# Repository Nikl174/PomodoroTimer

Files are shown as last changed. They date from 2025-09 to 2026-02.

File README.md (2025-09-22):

# Pomodoro Timer

A little USB A timer user for the [Pomdoro Technique](https://en.wikipedia.org/wiki/Pomodoro_Technique).

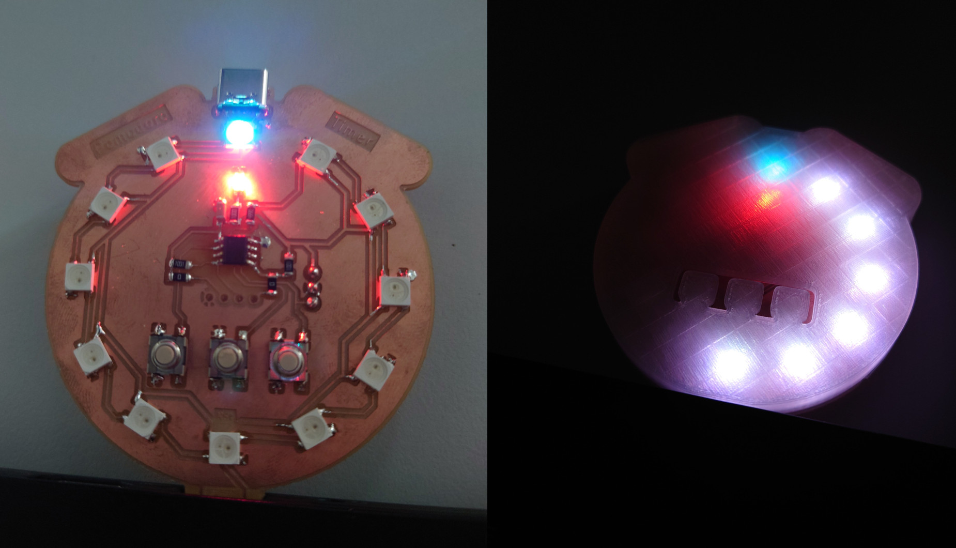
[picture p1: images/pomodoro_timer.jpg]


## Features

- small and powerful ATTiny412 as MCU
- 12 WS2813B RGB LEDs
- 3 Buttons
- I2C Header for playing around
- power over USB C or integrated USB A connector

## Structure

`pcb/`
: KiCAD Files for the electronic schematics and the routed layout

`code/`
: Arduino Code for a simple implementation of the pomodoro technique

`housing/`
: FreeCAD Model for a simple housing for the board

`doc/`
: Datasheets

## Dependencies

### Hardware

- [Components Library](https://gitlab.fabcloud.org/pub/libraries/electronics/kicad) - Component library used for the PCB
- [Serial D11C Programmer](https://gitlab.fabcloud.org/pub/programmers/programmer-serial-d11c) - UPDI Programmer used for flashing together with this [adapter](https://leomcelroy.com/svg-pcb/?file=hello.serial-UPDI.3.js), but also possible with e.g.:
    - [SWD+UART Board](https://gitlab.fabcloud.org/pub/programmers/swd-uart-adapter-xiao-rp2040)
    - [UPDI D11C](https://gitlab.fabcloud.org/pub/programmers/programmer-updi-d11c)
- [MegaTinyCore](https://github.com/SpenceKonde/megaTinyCore/) - arduino library used for programming the ATTiny412
- an arduino environment, more in [here](/code/README.md)
- [KiCAD](https://www.kicad.org/) for editing the PCB/ creating other production files
- [FreeCAD](https://www.freecad.org/) for editing the housing

## BOM Components

| Designator | Footprint | Quantity | Designation |
|---|---|---|---|
| U6,U8,U3,U9,U11,U10,U2,U12,U4,U7,U5,U13 | LED_ADDR_Worldsemi_WS2812B | 12 | WS2812B |
| R2,R7 | R_1206 | 2 | 0R |
| J2 | PinHeader_01x04_P2.54mm_Vertical_THT_D1.4mm | 1 | I2C Header |
| P1 | Conn_USB_A_Plain | 1 | Conn_USB_A_Plain |
| C3 | C_1206 | 1 | 100nF |
| R3 | R_1206 | 1 | 100R |
| SW3 | Button_Omron_B3SN_6.0x6.0mm | 1 | Restart |
| R6,R1 | R_1206 | 2 | 1kR |
| D4 | LED_1206 | 1 | Power LED |
| SW1 | Button_Omron_B3SN_6.0x6.0mm | 1 | Start/Stop |
| U1 | SOIC-8_3.9x4.9mm_P1.27mm | 1 | ATtiny412 |
| J1 | PinHeader_01x03_P2.54mm_Vertical_THT_D1.4mm | 1 | UPDI Flash Header |
| J3 | Conn_USB_C_Socket_GCT_USB4125-GF-A-0190 | 1 | Conn_USB_C_Socket_PowerOnly |
| R5 | R_1206 | 1 | 499R |
| SW2 | Button_Omron_B3SN_6.0x6.0mm | 1 | Skip |

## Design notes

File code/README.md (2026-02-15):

# Simple implementation of the Pomodoro timer in Arduion

- Initial '12' cycles colors

## Buttons:

| Button | Function | 
| --- | --- |
| Restart (right)| Cancels the Current Routine and Starts again |
| Start/Stop (middle)| Toggles running of the current round (pause or productivity time) |
| Skip (left) | Skips the currently running cycle|

## Structure

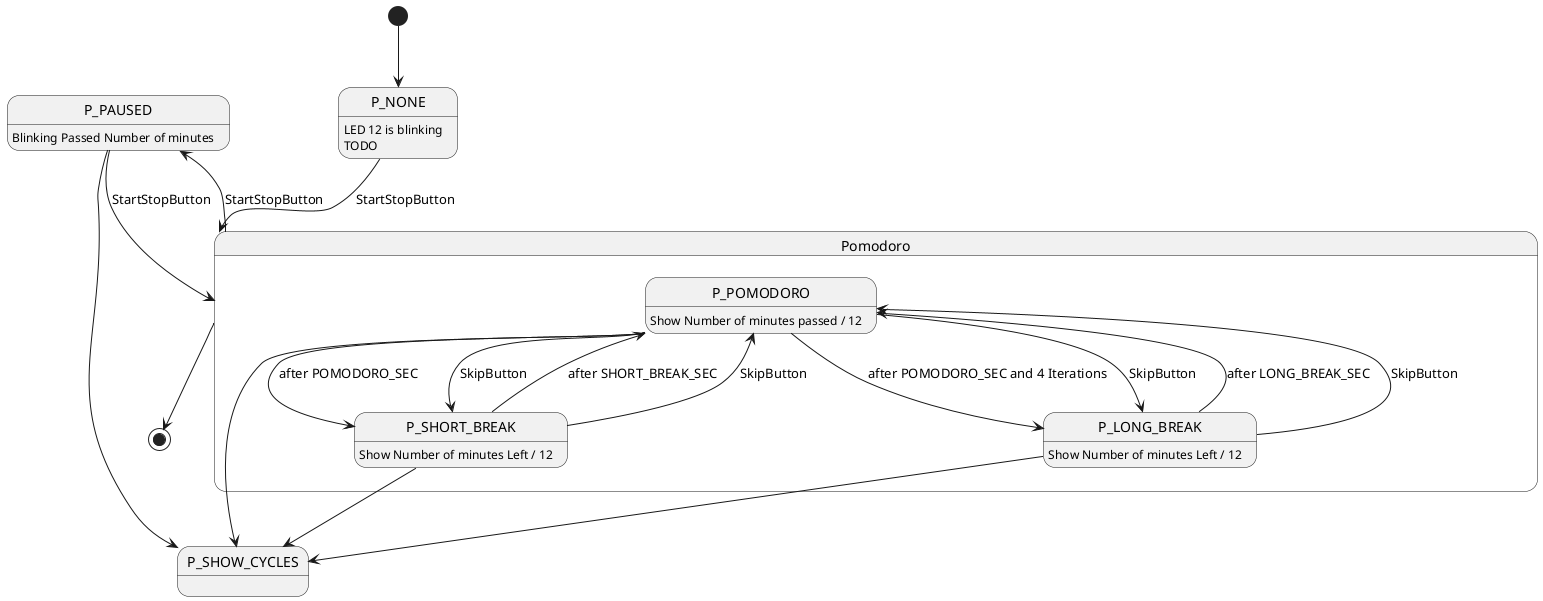
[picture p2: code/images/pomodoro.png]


- use the [`conf.h`](./conf.h) file to adjust the programms behavior

## Compile and Upload

### Dependencies

- [Arduino](https://www.arduino.cc/en/software/), ether
    - IDE (recommended: v1/legacy, but the newer one should also work)
    - arduino-cli
- [MegaTinyCore](https://github.com/SpenceKonde/megaTinyCore/) for the core implementation of the arduino API for the [ATtiny412](https://github.com/SpenceKonde/megaTinyCore/blob/master/megaavr/extras/ATtiny_x12.md)

### arduino-cli

0. Install the arduino-cli

1. First you need to setup your Arduino environment:

``` bash
# initialises the system configuration for arduino
# usually at '$HOME/.arduino15/' where 15 represents the version
arduino-cli config init
```

2. Next you need to download the core library

``` bash
# add the index from the MegaTinyCore index
arduino-cli config add board_manager.additional_urls http://drazzy.com/package_drazzy.com_index.json

# now install the megaTinyCore library
arduino-cli core install megaTinyCore:megaavr
```

3. Now compile like this:

``` bash
# compile with megaTinyCore for attiny412(atxy2) (or attiny212)
arduino-cli compile --fqbn megaTinyCore:megaavr:atxy2 code.ino
```

4. And then to upload it with the [Serial D11C Programmer](https://gitlab.fabcloud.org/pub/programmers/programmer-serial-d11c) (and [this adapter](https://leomcelroy.com/svg-pcb/?file=hello.serial-UPDI.3.js)) use this:

``` bash
# upload with the flasher on port '/dev/ttyACM0' for the attiny412 (atxy2) and the flasher is a 'serialupdi57k' (57000 Baudrate)
arduino-cli upload -p /dev/ttyACM0 --fqbn megaTinyCore:megaavr:atxy2 -P serialupdi57k code.ino
```

### Arduion IDE 1.X

TODO

##### Quentores Notes

- with the [Quentores](https://gitlab.fabcloud.org/pub/programmers/quentorres) you have a problem under Linux and MacOS mentioned [here](https://gitlab.fabcloud.org/pub/programmers/quentorres#linux-uart-target-issues)

```bash
python -m virtualenv .
source ./bin/activate.sh
pip install pymcuprog==3.16.8.40
#                                                       ___________________________________________________________________________ change this to your file
pymcuprog write -t uart -u /dev/ttyACM0 -d attiny412 -f $HOME/.cache/arduino/sketches/23D6BB44CFB64DF5516B4531B04243FE/code.ino.hex --erase --verify
```

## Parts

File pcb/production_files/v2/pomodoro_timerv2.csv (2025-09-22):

Id | Designator | Footprint | Quantity | Designation | Supplier and ref
1 | U6,U8,U3,U9,U11,U10,U2,U12,U4,U7,U5,U13 | LED_ADDR_Worldsemi_WS2812B | 12 | WS2812B
2 | R2,R7 | R_1206 | 2 | 0R
3 | J2 | PinHeader_01x04_P2.54mm_Vertical_THT_D1.4mm | 1 | I2C Header
4 | P1 | Conn_USB_A_Plain | 1 | Conn_USB_A_Plain
5 | C3 | C_1206 | 1 | 100nF
6 | R3 | R_1206 | 1 | 100R
7 | SW3 | Button_Omron_B3SN_6.0x6.0mm | 1 | Restart
8 | R6,R1 | R_1206 | 2 | 1kR
9 | D4 | LED_1206 | 1 | Power LED
10 | SW1 | Button_Omron_B3SN_6.0x6.0mm | 1 | Start/Stop
11 | U1 | SOIC-8_3.9x4.9mm_P1.27mm | 1 | ATtiny412
12 | J1 | PinHeader_01x03_P2.54mm_Vertical_THT_D1.4mm | 1 | UPDI Flash Header
13 | J3 | Conn_USB_C_Socket_GCT_USB4125-GF-A-0190 | 1 | Conn_USB_C_Socket_PowerOnly
14 | R5 | R_1206 | 1 | 499R
15 | SW2 | Button_Omron_B3SN_6.0x6.0mm | 1 | Skip

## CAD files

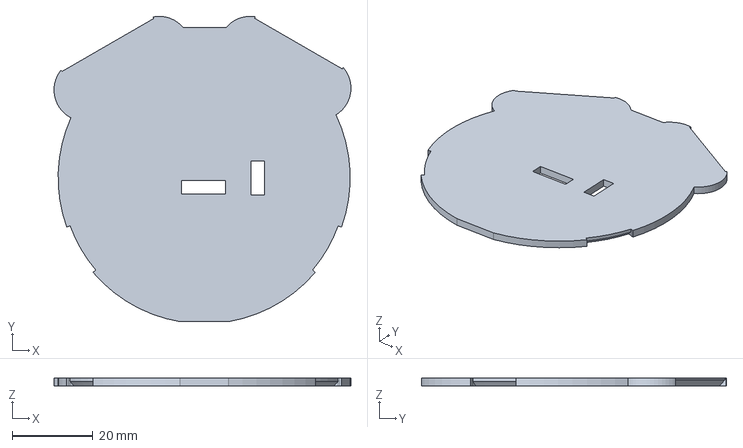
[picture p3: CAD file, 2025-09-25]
housing/Housing.FCStd
73.7 x 75.7 x 2.00 mm

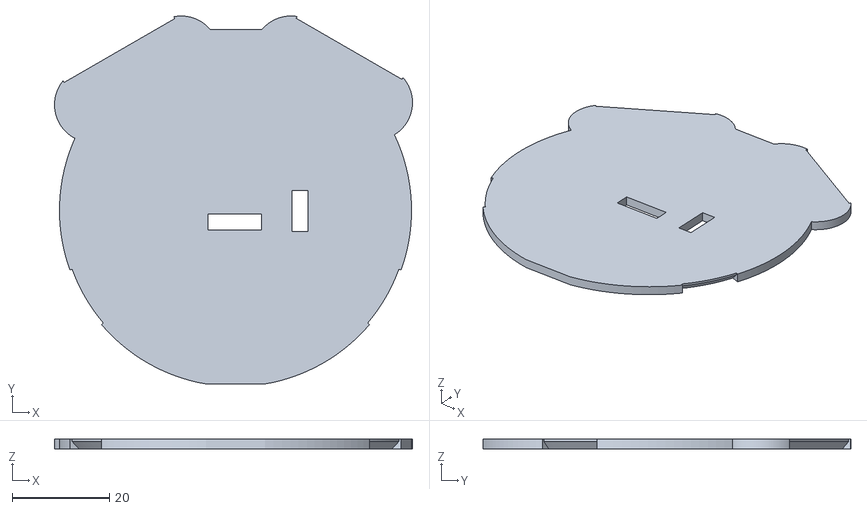
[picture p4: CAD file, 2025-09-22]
housing/STLs/Housing-BottomPlate.stl
73.7 x 75.7 x 2.00

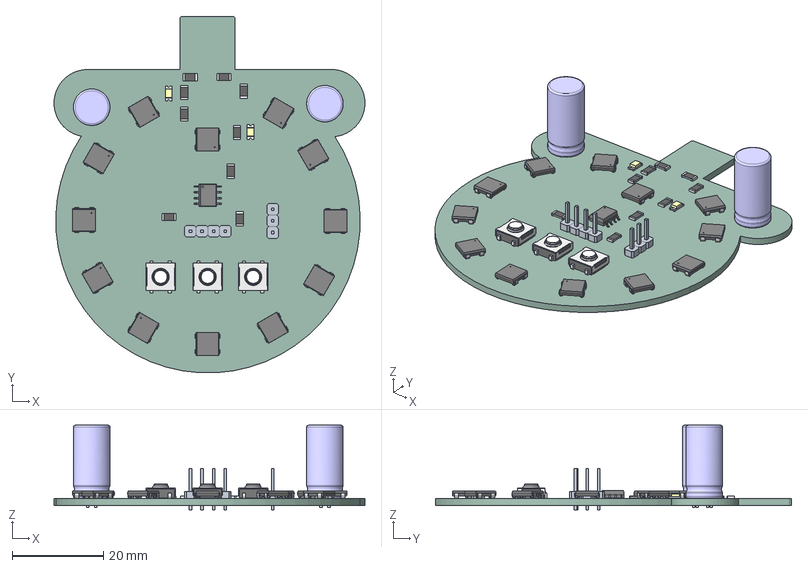
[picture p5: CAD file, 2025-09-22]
pcb/production_files/v2/pomodoro_timer2.step
68.1 x 78.0 x 18.5 mm
WS2812B_WDS x 12
pomodoro_timer2 1.2.1
pomodoro_timer2 1.2.2
pomodoro_timer2 1.2.3
pomodoro_timer2 1.2.4
Ceramic x 9
Contacts x 9
Contacts (Mirror #1) x 9
Overcoat x 9
Base x 5
Emmiter x 2
Contact_1 x 2
Contact_2 x 2
Wire x 2
Lead x 3
Button x 3
Cover x 3
Leads_Right x 4
Package
Dot
pomodoro_timer2 1.22.1
pomodoro_timer2 1.22.2
pomodoro_timer2 1.22.3
pomodoro_timer_PCB

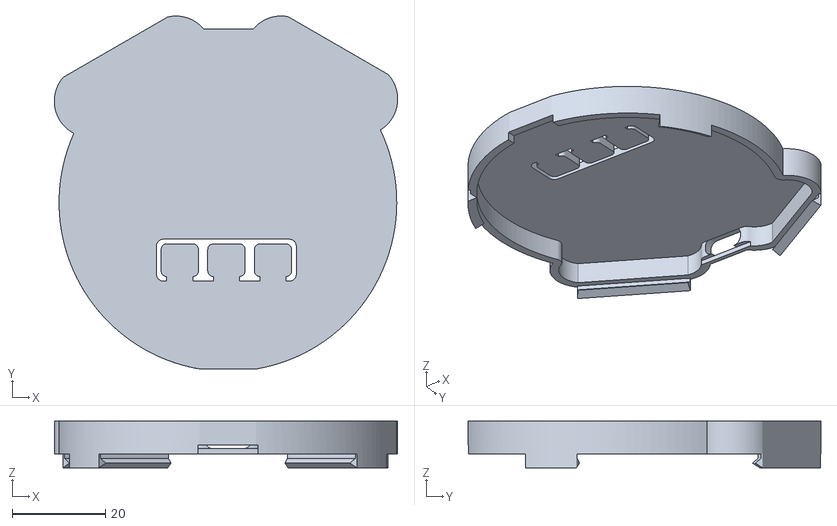
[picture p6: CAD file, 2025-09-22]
housing/STLs/Housing-TopHousing2.stl
73.7 x 75.7 x 10.0

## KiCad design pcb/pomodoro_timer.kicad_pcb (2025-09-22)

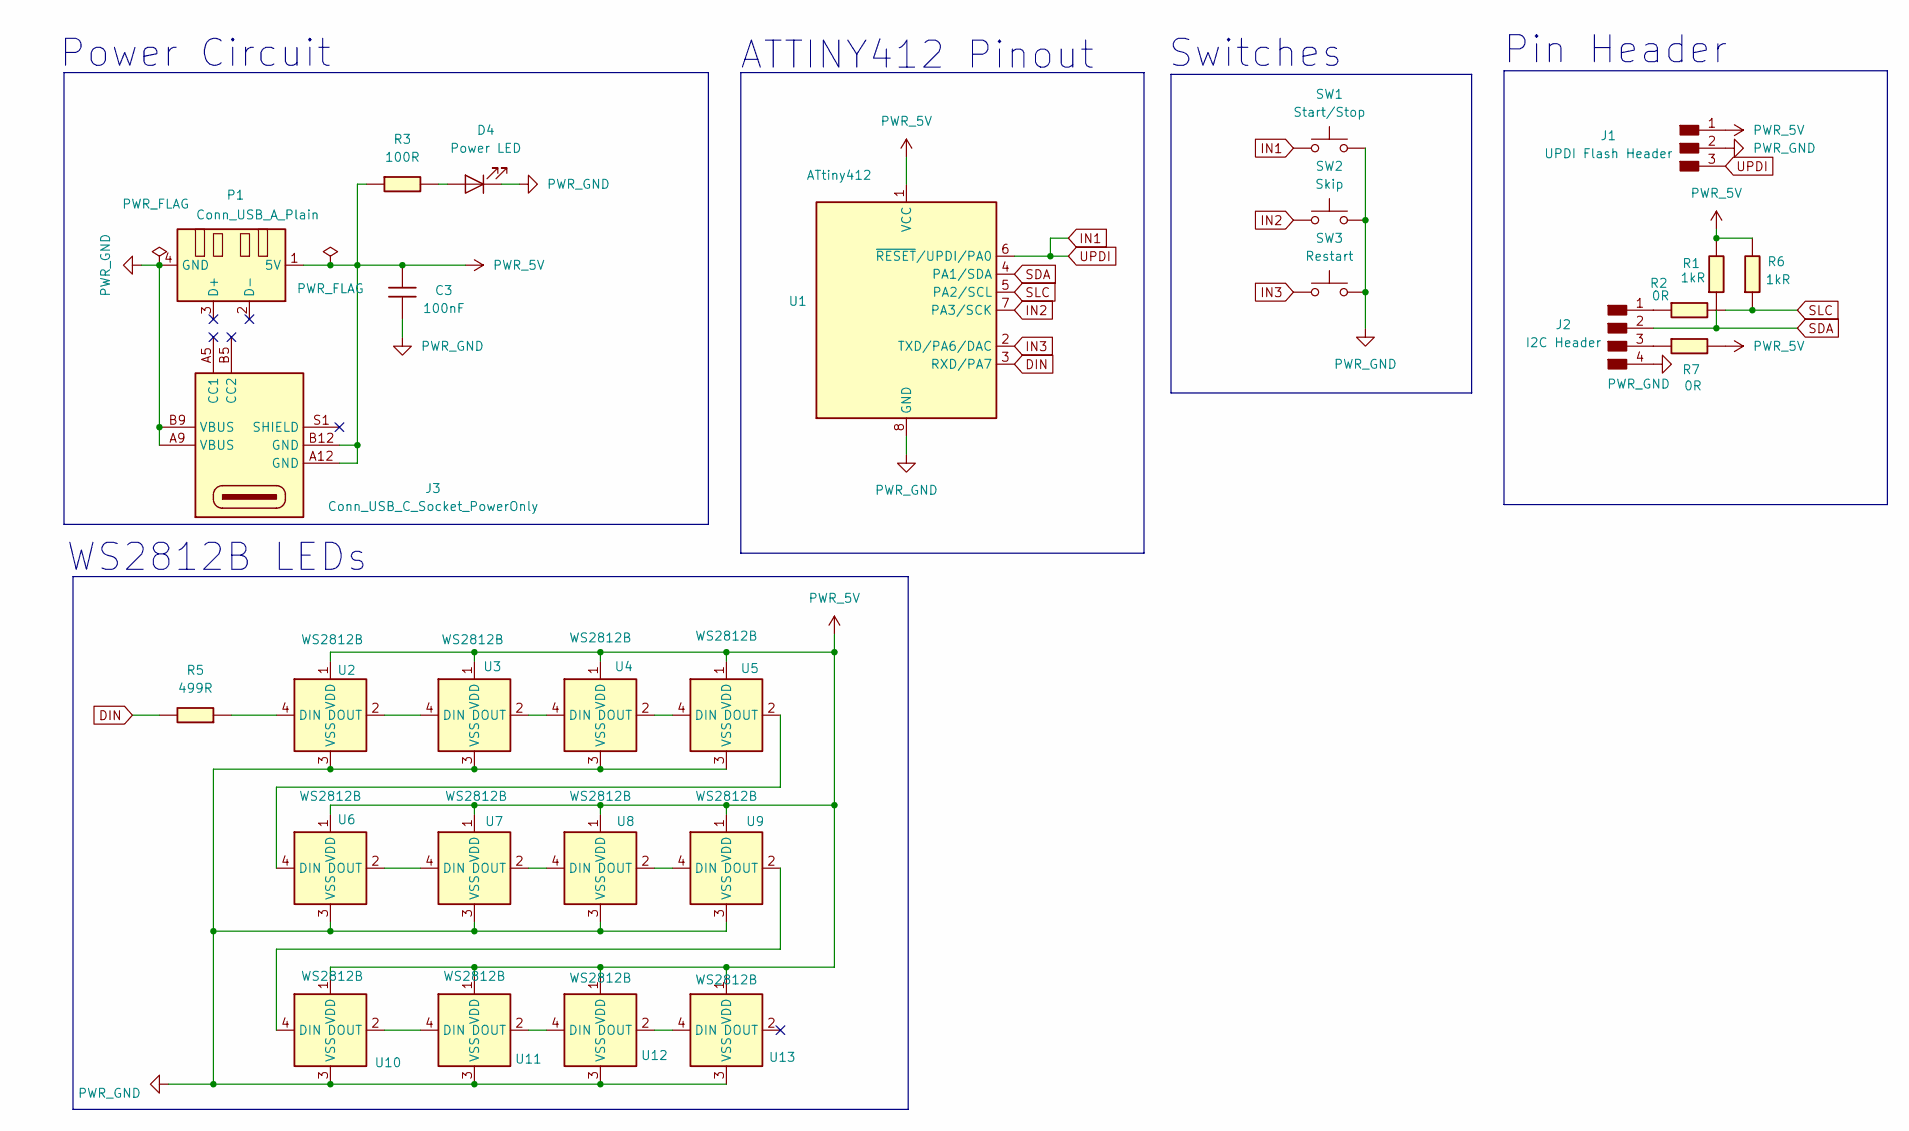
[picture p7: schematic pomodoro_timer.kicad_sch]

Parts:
C3: 100nF; C_1206
D4: Power LED; LED_1206
J1: UPDI Flash Header; PinHeader_01x03_P2.54mm_Vertical_THT_D1.4mm
J2: I2C Header; PinHeader_01x04_P2.54mm_Vertical_THT_D1.4mm
J3: Conn_USB_C_Socket_PowerOnly; Conn_USB_C_Socket_GCT_USB4125-GF-A-0190
P1: Conn_USB_A_Plain
R1, R6: 1kR; R_1206
R2, R7: 0R; R_1206
R3: 100R; R_1206
R5: 499R; R_1206
SW1: Start/Stop; Button_Omron_B3SN_6.0x6.0mm
SW2: Skip; Button_Omron_B3SN_6.0x6.0mm
SW3: Restart; Button_Omron_B3SN_6.0x6.0mm
U1: ATtiny412; SOIC-8_3.9x4.9mm_P1.27mm
U2, U3, U4, U5, U6, U7, U8, U9, U10, U11, U12, U13: WS2812B; LED_ADDR_Worldsemi_WS2812B

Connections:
DIN: R5.1, U1.3 (RXD/PA7)
IN1: J1.3, SW1.1, U1.6 (~RESET/UPDI/PA0)
IN2: SW2.1, U1.7 (PA3/SCK)
IN3: SW3.1, U1.2 (TXD/PA6/DAC)
unnamed: D4.2 (A), R3.1
unnamed: J2.1, R2.2
unnamed: J2.3, R7.2
unnamed: R5.2, U2.4 (DIN)
unnamed: U2.2 (DOUT), U3.4 (DIN)
unnamed: U3.2 (DOUT), U4.4 (DIN)
unnamed: U4.2 (DOUT), U5.4 (DIN)
unnamed: U5.2 (DOUT), U6.4 (DIN)
unnamed: U6.2 (DOUT), U7.4 (DIN)
unnamed: U7.2 (DOUT), U8.4 (DIN)
unnamed: U8.2 (DOUT), U9.4 (DIN)
unnamed: U9.2 (DOUT), U10.4 (DIN)
unnamed: U10.2 (DOUT), U11.4 (DIN)
unnamed: U11.2 (DOUT), U12.4 (DIN)
unnamed: U12.2 (DOUT), U13.4 (DIN)
PWR_5V: C3.1, J1.1, J3.A12 (GND), J3.B12 (GND), P1.1 (5V), R1.1, R3.2, R6.1, R7.1, U1.1 (VCC), U2.1 (VDD), U3.1 (VDD), U4.1 (VDD), U5.1 (VDD), U6.1 (VDD), U7.1 (VDD), U8.1 (VDD), U9.1 (VDD), U10.1 (VDD), U11.1 (VDD), U12.1 (VDD), U13.1 (VDD)
PWR_GND: C3.2, D4.1 (K), J1.2, J2.4, J3.A9 (VBUS), J3.B9 (VBUS), P1.4 (GND), SW1.2, SW2.2, SW3.2, U1.8 (GND), U2.3 (VSS), U3.3 (VSS), U4.3 (VSS), U5.3 (VSS), U6.3 (VSS), U7.3 (VSS), U8.3 (VSS), U9.3 (VSS), U10.3 (VSS), U11.3 (VSS), U12.3 (VSS), U13.3 (VSS)
SDA: J2.2, R1.2, U1.4 (PA1/SDA)
SLC: R2.1, R6.2, U1.5 (PA2/SCL)

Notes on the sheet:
Pin Header
Power Circuit
ATTINY412 Pinout
WS2812B LEDs
Switches

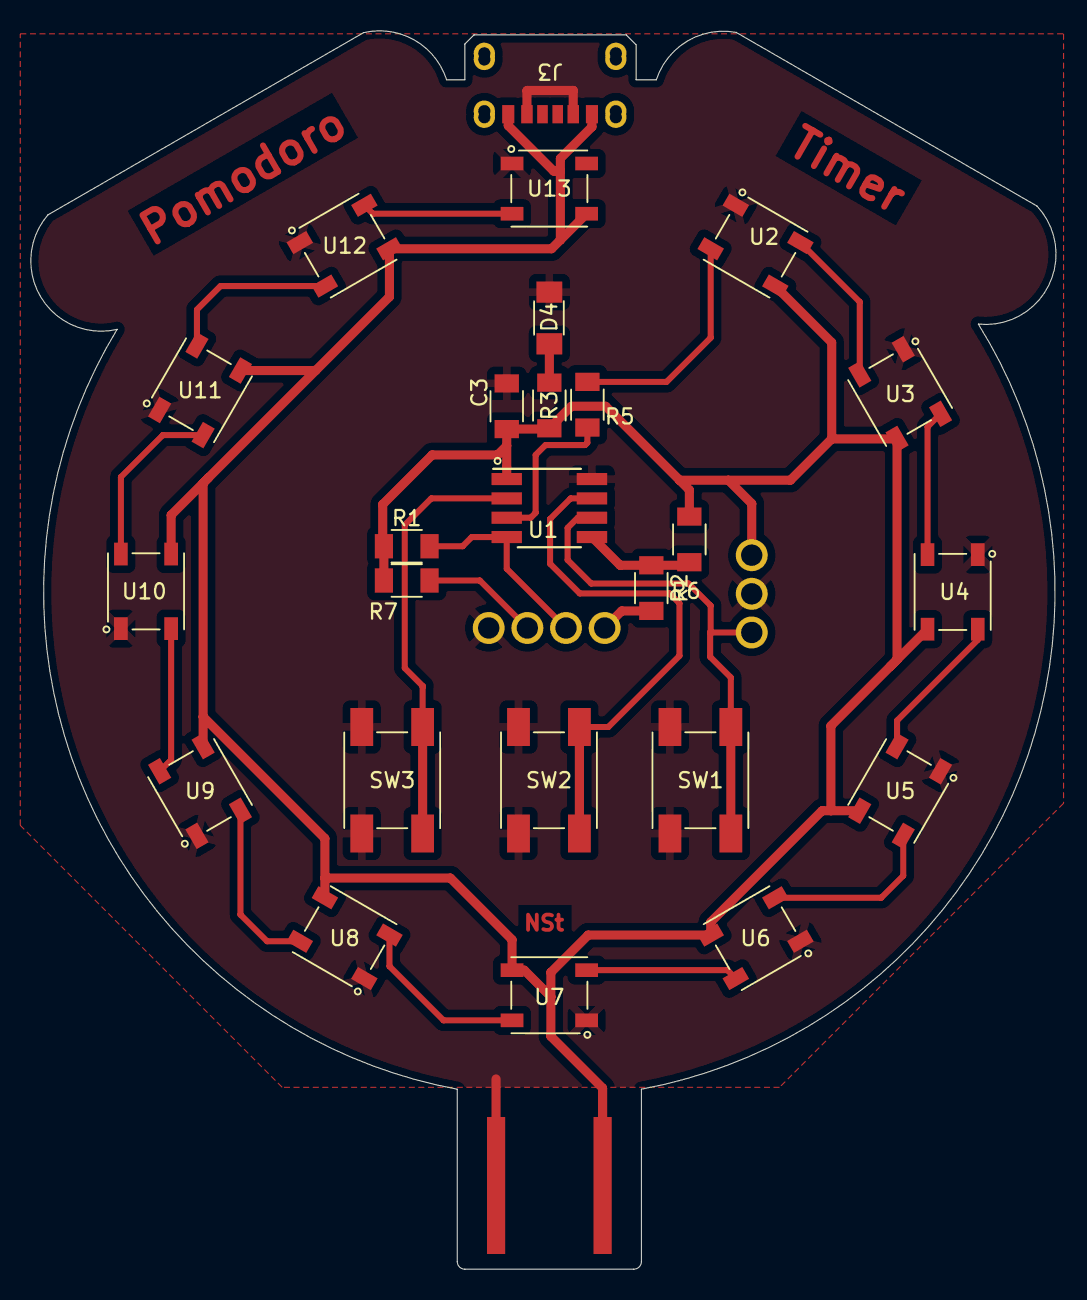
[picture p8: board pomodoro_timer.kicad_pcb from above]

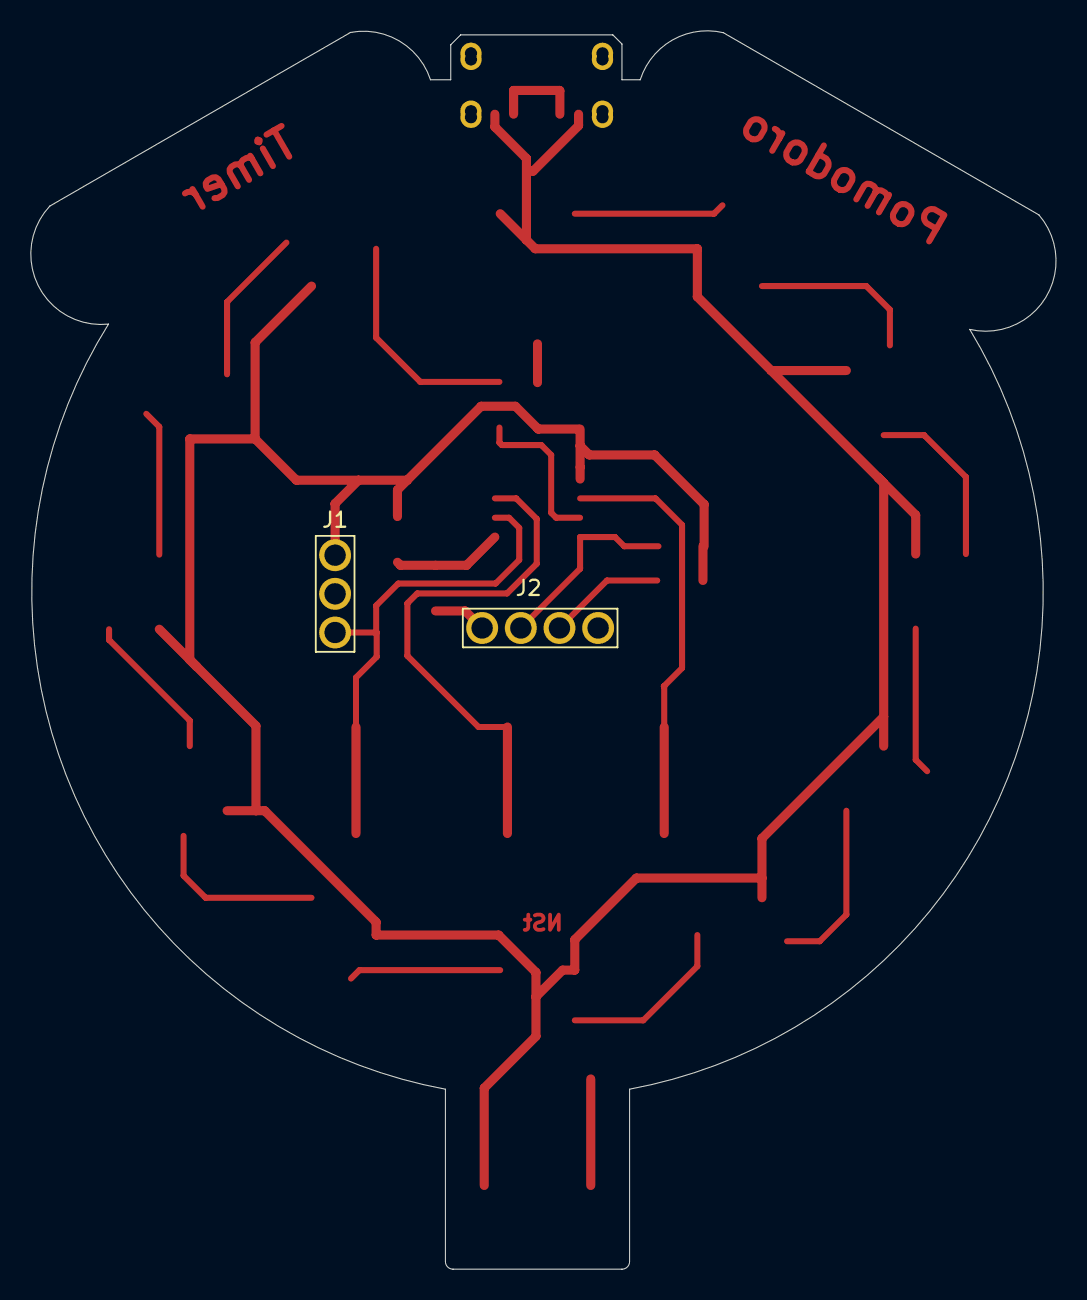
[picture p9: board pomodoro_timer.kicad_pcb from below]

Board: 2 copper layers, 67.4 x 81.4 mm, 28 parts (2 on the bottom side), 23 nets.

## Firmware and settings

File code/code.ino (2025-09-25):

// NeoPixel Ring simple sketch (c) 2013 Shae Erisson
// released under the GPLv3 license to match the rest of the AdaFruit NeoPixel library

#include <tinyNeoPixel_Static.h>
#include "conf.h"


#ifdef DEBUG
#define LOG_PRINTF(format, ...) printf(format, __VA_ARGS__);
#define LOG(format) printf(format);
#else
#define LOG_PRINTF(format, ...)
#define LOG(format)
#endif

/*! \struct Buttons
 *  \brief Counting struct for the number of button presses
 *
 *  TODO
 */
struct Buttons {
  unsigned int start_stop;
  unsigned int skip;
  unsigned int restart;
};

/*! \enum PomodoroState
 *
 *  Encodes the current Interval State That is running
 */
enum PomodoroState {
  P_STATE_POMODORO,
  P_STATE_SHORT_BREAK,
  P_STATE_LONG_BREAK,
  P_STATE_NONE
};

/*! \struct Pomodoro
 *  \brief State information for the pomodoro cycle
 *
 *  TODO
 */
struct Pomodoro {
  unsigned int intervals_done;
  unsigned long start_ms;
  unsigned int interval_sec_passed;
  unsigned int pomodoro_sec;
  unsigned int short_break_sec;
  unsigned int long_break_sec;
  unsigned int long_break_intervals;
  PomodoroState interval_state;
};

struct Visualize {
  unsigned int none_r;
  unsigned int none_g;
  unsigned int none_b;
  int brightness;
  int factor;
};

Visualize vis;
byte pixelarray[NUMPIXELS * 3];
Buttons buts;
Pomodoro pom;
tinyNeoPixel pixels = tinyNeoPixel(NUMPIXELS, NEO_PIN, NEO_GRB + NEO_KHZ800, pixelarray);

// \brief update passed seconds in the pomodoro state of the current interval
// TODO handle for integer overflow of millis
void pomodoro_update_passed_sec(Pomodoro *pom) {

  if (pom->start_ms) {
    // difference between start of timer and now in s
    unsigned long new_sec = (millis() - pom->start_ms) / 1000;

    pom->interval_sec_passed += new_sec;
    // if more then one second, set new point (because of the above +=)
    if (new_sec) pom->start_ms = millis();

    LOG_PRINTF("Updated Interval by '%i' to '%i'", new_sec, pom->interval_sec_passed);
  } else {
    LOG("Could not update passed seconds, interval not started!");
  }
}

// \brief toggles between start and stopping of the timer and initialy starts the pomodoro cycle
// done by setting a starting-point (in ms)
void pomodoro_start_stop(Pomodoro *pom) {
  switch (pom->interval_state) {
    case P_STATE_NONE:
      // start the cycle by saving the current milliseconds
      pom->start_ms = millis();
      pom->interval_state = P_STATE_POMODORO;
      LOG("Starting Pomodoro Timer");
      break;
    default:
      // currently in an interval
      if (pom->start_ms) {
        // pomodoro is running, stop by erasing start_ms
        pomodoro_update_passed_sec(pom);
        pom->start_ms = 0;
        LOG("Stopping current interval");
      } else {
        // interval is stopped, save the start point
        pom->start_ms = millis();
        LOG("Continue current interval");
      }
  };
}

// \brief Advances the Pomodoro State Machine
// returns 1 if the state changed
// pomodoro_update_passed_sec(pom) should be called before
int pomodoro_update_state(Pomodoro *pom, bool skip) {
  switch (pom->interval_state) {
    case P_STATE_POMODORO:
      if (pom->interval_sec_passed >= pom->pomodoro_sec || skip) {
        // end if interval

        // pomodoro done, increase counter
        if (!skip) pom->intervals_done++;

        // check long break
        if (pom->intervals_done && pom->intervals_done % pom->long_break_intervals == 0) {
          // long break qualified
          pom->interval_state = P_STATE_LONG_BREAK;
        } else {
          pom->interval_state = P_STATE_SHORT_BREAK;
        }
        // reset time and passed seconds for new state
        pom->interval_sec_passed = 0;
        pom->start_ms = millis();
        return 1;
      }
      break;
    case P_STATE_SHORT_BREAK:
      if (pom->interval_sec_passed >= pom->short_break_sec || skip) {
        // end if interval
        pom->interval_state = P_STATE_POMODORO;
        // reset time and passed seconds for new state
        pom->interval_sec_passed = 0;
        pom->start_ms = millis();
        return 1;
      }
      break;
    case P_STATE_LONG_BREAK:
      if (pom->interval_sec_passed >= pom->long_break_sec || skip) {
        // end if interval

        pom->interval_state = P_STATE_POMODORO;
        // reset time and passed seconds for new state
        pom->interval_sec_passed = 0;
        pom->start_ms = millis();
        return 1;
      }
      break;
    default:
      // state not changed
      return 0;
  }
}

void visualise_pomodoro_time(Pomodoro *pom, tinyNeoPixel *pixel, Visualize *visual) {
  float scaled_time;

  // visualisation depends on pomodoro state
  switch (pom->interval_state) {
    case P_STATE_POMODORO:

      // scale time to the number of LEDS
      //            ______________________________ Scale Factor
      scaled_time = ((float)NUMPIXELS / pom->pomodoro_sec) * pom->interval_sec_passed;
      // set all pixel that are in the time interval with right color
      for (int i = 0; i < NUMPIXELS; i++) {

        if (scaled_time >= i)
          pixel->setPixelColor(i, POMODORO_COLOR((*pixel)));
      }

      break;
    case P_STATE_LONG_BREAK:

      // scale time to the number of LEDS
      //            ______________________________ Scale Factor
      scaled_time = ((float)NUMPIXELS / pom->long_break_sec) * pom->interval_sec_passed;
      // set all pixel that are in the time interval with right color
      for (int i = 0; i < NUMPIXELS; i++) {

        if (scaled_time >= i)
          pixel->setPixelColor(i, LONG_BREAK_COLOR((*pixel)));
      }

      break;
    case P_STATE_SHORT_BREAK:

      // scale time to the number of LEDS
      //            ______________________________ Scale Factor
      scaled_time = ((float)NUMPIXELS / pom->short_break_sec) * pom->interval_sec_passed;
      // set all pixel that are in the time interval with right color
      for (int i = 0; i < NUMPIXELS; i++) {

        if (scaled_time >= i)
          pixel->setPixelColor(i, SHORT_BREAK_COLOR((*pixel)));
      }

      break;
  }
  // adjust brightness afterwards and show (send to LEDs)
  pixel->setBrightness(visual->brightness);
  pixel->show();

  // reset color values for pixels afterwards, but do not show!
  for (int i = 0; i < NUMPIXELS; i++) pixel->setPixelColor(i, 0, 0, 0);
}

void count_button_start() {
  buts.start_stop++;
}
void count_button_skip() {
  buts.skip++;
}
void count_button_restart() {
  buts.restart++;
}


void setup() {


  buts = {
    .start_stop = 0,
    .skip = 0,
    .restart = 0,
  };
  pom = {
    .intervals_done = 0,
    .start_ms = 0,
    .interval_sec_passed = 0,
    .pomodoro_sec = POMODORO_SEC,
    .short_break_sec = SHORT_BREAK_SEC,
    .long_break_sec = LONG_BREAK_SEC,
    .long_break_intervals = LONG_BREAK_INTERVALS,
    .interval_state = P_STATE_NONE,
  };
  vis = {
    .none_r = 255,
    .none_g = 0,
    .none_b = 0,
    .brightness = BRIGHTNESS,
    .factor = -COLOR_SCALE,
  };


  // activate internal pull-up for buttons
  pinMode(SKIP_PIN, INPUT_PULLUP);
  pinMode(START_PIN, INPUT_PULLUP);
  pinMode(RESTART_PIN, INPUT_PULLUP);
  pinMode(NEO_PIN, OUTPUT);
  // register interrupts for buttons
  attachInterrupt(digitalPinToInterrupt(START_PIN), count_button_start, RISING);
  attachInterrupt(digitalPinToInterrupt(SKIP_PIN), count_button_skip, RISING);
  attachInterrupt(digitalPinToInterrupt(RESTART_PIN), count_button_restart, RISING);
}

void loop() {

  // read each pin, ! because of pull up
  // comment because interrupt for pins
  // buts.start_stop = !digitalRead(START_PIN);
  // buts.skip = !digitalRead(SKIP_PIN);
  // buts.restart = !digitalRead(RESTART_PIN);


  // update passed seconds and pomodoro state, giving the skip button to maybe skip the current state
  pomodoro_update_passed_sec(&pom);
  pomodoro_update_state(&pom, buts.skip);
  buts.skip = 0;

  // toggle start/stop when button was pressed
  if (buts.start_stop) {
    pomodoro_start_stop(&pom);
    buts.start_stop = 0;
  }

  // completely reset the pomodoro timer
  if (buts.restart) {
    // TODO show Cycles while pressed
    pom.interval_sec_passed = 0;
    pom.intervals_done = 0;
    pom.start_ms = 0;
    pom.interval_state = P_STATE_NONE;

    buts.restart = 0;
  }

  // 12 as an idle color cycle
  pixels.setPixelColor(NONE_LED, pixels.Color(vis.none_r, vis.none_g, vis.none_b));

  // cycle through all colors
  if (vis.none_b == 0 && vis.none_r > 0) {
    vis.none_g += COLOR_SCALE;
    vis.none_r -= COLOR_SCALE;
  } else if (vis.none_r == 0 && vis.none_g > 0) {
    vis.none_b += COLOR_SCALE;
    vis.none_g -= COLOR_SCALE;
  } else if (vis.none_g == 0 && vis.none_b > 0) {
    vis.none_r += COLOR_SCALE;
    vis.none_b -= COLOR_SCALE;
  }

  if (!pom.start_ms) {
    // timer is paused, pulse brightness
    if (vis.brightness >= BRIGHTNESS) {
      vis.factor = -COLOR_SCALE;
    } else if (vis.brightness <= COLOR_SCALE) {
      vis.factor = COLOR_SCALE;
    }
    vis.brightness += vis.factor;
  } else {
    vis.brightness = BRIGHTNESS;
  }


  // show a loading circle for the current passed time in the interval
  visualise_pomodoro_time(&pom, &pixels, &vis);

  delay(DELAY_MS);
}

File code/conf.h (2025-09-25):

#ifndef CONF_H

#define CONF_H

// #define LONG_BREAK_SEC 1200 // 20 min
// #define SHORT_BREAK_SEC 300 // 5 min
// #define POMODORO_SEC 1500   // 25 min
// times for the intervals
#define LONG_BREAK_SEC 24 // 20 min
#define SHORT_BREAK_SEC 6 // 5 min
#define POMODORO_SEC 24   // 25 min
// number of pomodoro intervals until the long break is started
#define LONG_BREAK_INTERVALS 4

// Which pin on the Arduino is connected to the NeoPixels?
#define NEO_PIN 1
#define SKIP_PIN 0
#define START_PIN 4
#define RESTART_PIN 5

// How many NeoPixels are attached to the Arduino?
#define NUMPIXELS 12

// update delay, currently determines the responsiveness
#define DELAY_MS 100

// color of the pomodoro visualisation, 0 - 255, (R, G, B)
#define POMODORO_COLOR(pixels) pixels.Color(155, 155, 155)
#define SHORT_BREAK_COLOR(pixels) pixels.Color(155, 155, 0)
#define LONG_BREAK_COLOR(pixels) pixels.Color(0, 155, 155)

// ID of the LED constantly changing color
#define NONE_LED 11

// scale factor for brightness and color
#define COLOR_SCALE 3

// initial brightness value
#define BRIGHTNESS 80

// comment out to remove debug messages
// #define DEBUG

#endif /* end of include guard: CONF_H */

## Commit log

2025-09-22 added housing for PCB
    [Housing-BottomPlate.stl, Housing-TopHousing2.stl, Housing.FCStd]
2025-09-22 added code for simple pomodoro-timer in arduino + uml state diagramm
2025-09-22 PCB: updated schematics and routing
    [pomodoro_timer.kicad_pcb, pomodoro_timer.kicad_sch]
2025-09-22 added production files
    [pomodoro_timer.csv, pomodoro_timer2.step, pomodoro_timerv2.csv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]
2025-09-22 moved pcb files to other directory
    [pomodoro_timer.csv, pomodoro_timer.kicad_pcb, pomodoro_timer.kicad_sch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]
2025-09-22 updated README, added KiCAD tutorial Project, improved gitignores
    [pomodoro_timer.kicad_pcb, pomodoro_timer.kicad_sch]
2025-09-22 Fixed filename and added doc
    [code.ino]
2025-09-25 code: fixed error: state change and added pause brightness change
    [code.ino, conf.h]
2025-09-25 housing: improved clamps
    [Housing.FCStd]
2025-09-25 removed tutorial files
    [pomodoro_timer.kicad_pcb, pomodoro_timer.kicad_sch]
2025-09-25 code: improved doc and added interrupt implementation
